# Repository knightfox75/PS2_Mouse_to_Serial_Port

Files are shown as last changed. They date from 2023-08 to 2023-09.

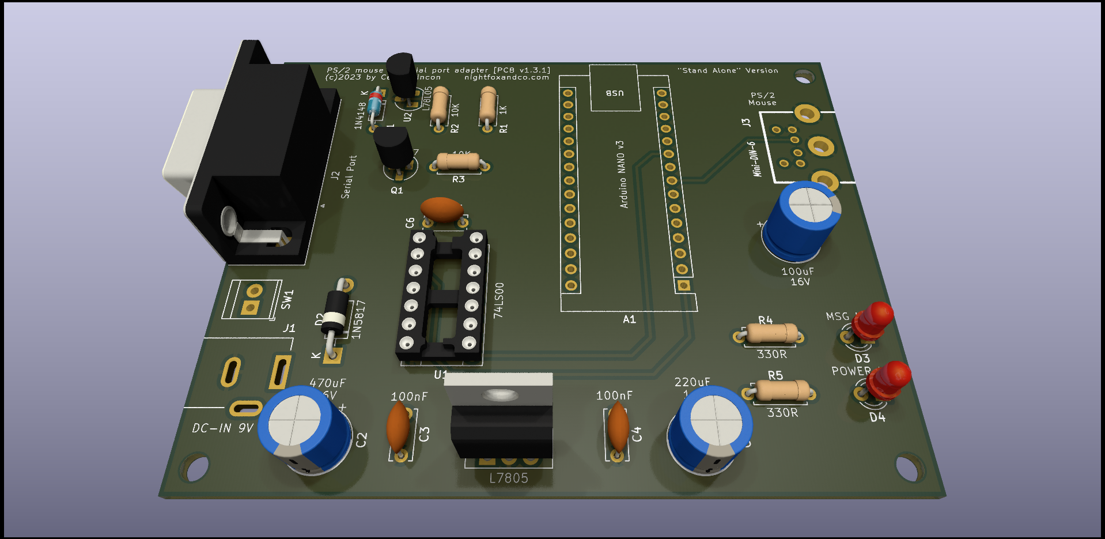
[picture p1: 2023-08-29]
schematics/Stand_Alone/PBC_preview/ps2_mouse_to_serial_port_adapter_stand_alone_3d.png

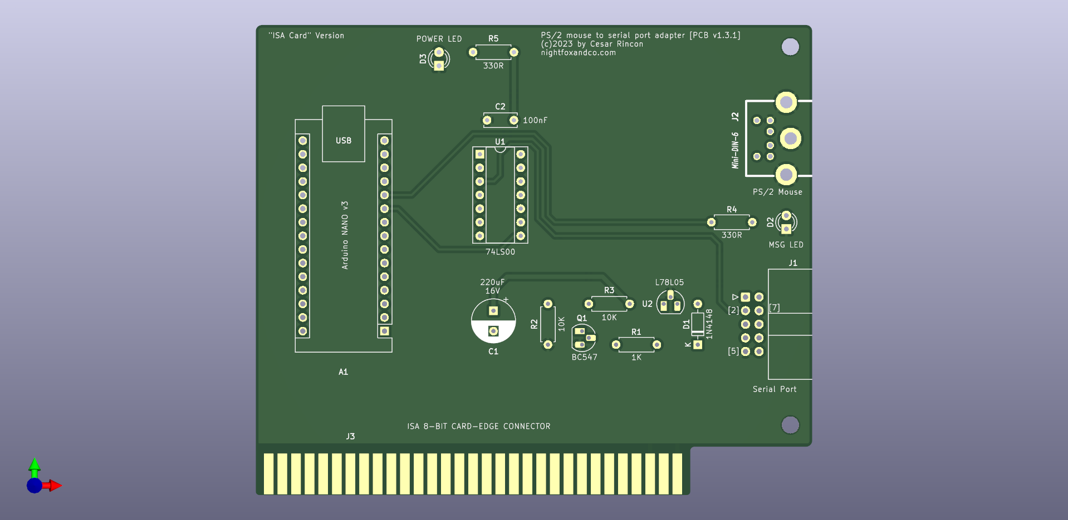
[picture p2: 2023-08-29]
schematics/ISA_Card/PBC_preview/ps2_mouse_to_serial_port_adapter_ISA_card_front.png

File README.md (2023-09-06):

# PS2_Mouse_to_Serial_Port
Un convertidor para conectar un ratón PS/2 a un puerto serie (RS-232).

1. Introducción
--------------------------------------------------------------------------------
Los ratones con conexión DB9 para puerto serie cada vez son más difíciles de encontrar (y más caros), lo que puede suponer un problema si necesitamos emplear uno en un ordenador clásico que solo disponga del puerto serie para su conexión. Después de investigar unas horas, encontré varias opciones comerciales y un par de proyectos open source que, usando placas Arduino, permitían la conexión de un ratón PS/2, o USB compatible con el protocolo PS/2 a un puerto serie.

https://github.com/Lameguy64/ps2serial
 
https://github.com/kristopher/PS2-Mouse-Arduino

Una vez documentado sobre estos proyectos y realizando un primer prototipo funcional de los mismos, decidí realizar mi propia versión del conversor.

2. Como funciona
--------------------------------------------------------------------------------
Básicamente la placa Arduino se encarga de prácticamente todo el trabajo, necesitando solo un poco de electrónica externa para su funcionamiento. Una librería de interacción con el protocolo PS/2 no permite leer la señal codificada procedente del ratón con las entradas. Dicha información se codifica en un paquete de datos en el formato que esperan los drivers de ratón mas comunes y se envían al puerto serie. Además, se monitorea la señal RTS del puerto serie por si se solicita el reinicio del envío de datos.

3. Hardware usado en el prototipo
--------------------------------------------------------------------------------
Se han realizado dos prototipos de prueba, usando las placas Arduino UNO R3 y Arduino NANO, funcionando ambas placas perfectamente. El resto de electrónica sirve para la adaptación de las señales que circulan por el puerto serie, ofreciendo cierto nivel de aislamiento y protección entre este puerto y la placa Arduino. Además, se incorporan dos diodos LED indicadores de estado, para el monitoreo del comportamiento del prototipo.

4. Que indican los LED’s de estado
--------------------------------------------------------------------------------
En mi caso he usado un LED rojo para el indicador de alimentación y un LED amarillo para el indicador de estado. Dicho indicador nos proporciona cierta información en el momento del arranque del adaptador, así como de su funcionamiento. Al encender el adaptador, si no puede detectar un ratón compatible conectado, quedará encendido de manera permanente. Dicho LED de estado parpadeará de manera intermitente una vez por segundo si ha detectado un ratón, pero no es posible iniciar la comunicación siguiendo el protocolo PS/2. Si el proceso de inicio se realiza correctamente, este LED emitirá 3 parpadeos, uno largo seguido de 2 mas cortos. Una vez iniciado el adaptador, si movemos el ratón, observaremos que este LED parpadea regularmente, quedando encendido mientras mantengamos pulsado alguno de los 3 botones del ratón. Si movemos la rueda de scroll, tambien emitira un parpadeo.
Si se recibe desde el puerto serie la señal RTS, este LED emitirá un parpadeo de aproximadamente medio segundo. Esto nos permite verificar que el driver ha detectado correctamente nuestro adaptador.

5. Capacidades extendidas
--------------------------------------------------------------------------------
Dado que este proyecto (en especial la placa ISA) está destinado a ordenadores sin puerto PS/2 (normalmente 486 y anteriores), usando el sistema operativo MS-DOS o Windows 3.11 y anteriores, junto con el hecho de que actualmente casi todos los ratones PS/2 son ópticos y disponen de la rueda de scroll, sumándole que para estos ordenadores casi ningún programa hace uso de la rueda de scroll, he decidido usar dicha rueda para ajustar a tiempo real la velocidad de desplazamiento del cursor. Dado que, según la resolución de pantalla, programa o modelo de ratón esta puede ser diferente, creo que es una característica útil. La velocidad seleccionada se conservará hasta que apaguemos el adaptador (o el ordenador en el caso de la placa ISA), no viendose afectada por el reinicio del sistema. Si queremos guardar la velocidad actual de manera permanente, deberemos de mantener pulsados los botones izquierdo y derecho de manera simultanea durante 5 segundos, observando que el LED de estado se apaga transcurrido ese tiempo. Esto nos indica que la configuración de ha almacenado de manera correcta. Si en algún momento deseamos restaurar la configuración por defecto, deberemos de mantener presionados ambos botones durante 10 segundos, el LED de estado se apagará a los 5 segundos, volviéndose a encender transcurridos 10 segundos. Esto indicará que la configuración se ha restaurado y almacenado con éxito.

6. Precauciones
--------------------------------------------------------------------------------
- Conectar y desconectar siempre el ratón al puerto PS/2 con el adaptador desconectado. La conexión o desconexión del ratón con el adaptador conectado a la alimentación podría causar daños al ratón y al propio adaptador. Esto también se aplica a la conexión del adaptador con el puerto serie del ordenador, siendo muy recomendable que todas las conexiones se realicen con los equipos apagados.
- Cualquier dispositivo conectado al puerto RS-232 del ordenador puede causar daños a dicho puerto o al dispositivo si este tiene algún error de montaje, por lo que se recomienda que repaséis 3 veces las conexiones antes de conectarlo a vuestro ordenador.
- Aplicable a la versión ISA, en ningún caso actualicéis el firmware del modulo Arduino con la tarjeta ISA insertada en la placa base. Retirar la tarjeta ISA o el módulo Arduino antes de conectarlo al puerto USB para su actualización. De no hacerlo, se corre el riesgo de dañar el módulo Arduino la propia placa base del ordenador.

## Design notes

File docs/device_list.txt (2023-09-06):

-------------------------------------------------------------------------------------------------------------------------
MODEL						|	POWER UP	|	DETECTED	|	MOVEMENT	|	2 BUTTONS	|	3RD BUTTON	|	WHEEL	|
-------------------------------------------------------------------------------------------------------------------------
PERIMICE-209				|	YES			|	YES			|	GOOD		|	YES			|	YES			|	YES		|
-------------------------------------------------------------------------------------------------------------------------
GENIUS EASYMOUSE			|	YES			|	YES			|	BAD			|	NO			|	N/A			|	N/A		|
-------------------------------------------------------------------------------------------------------------------------
HP 537748-001				|	YES			|	YES			|	GOOD		|	YES			|	YES			|	YES		|
-------------------------------------------------------------------------------------------------------------------------
LYNX-M9	(USB)				|	YES			|	YES			|	GOOD		|	YES			|	YES			|	YES		|
-------------------------------------------------------------------------------------------------------------------------
LOGITECH USB WHELLMOUSE		|	YES			|	YES			|	GOOD		|	NO			|	NO			|	YES		|
-------------------------------------------------------------------------------------------------------------------------
SATYCON 3D MOUSE			|	YES			|	YES			|	ACCEPTABLE	|	YES			|	YES			|	YES		|
-------------------------------------------------------------------------------------------------------------------------
LOGITECH M-SBJ96			|	YES			|	YES			|	GOOD		|	YES			|	YES			|	YES		|
-------------------------------------------------------------------------------------------------------------------------

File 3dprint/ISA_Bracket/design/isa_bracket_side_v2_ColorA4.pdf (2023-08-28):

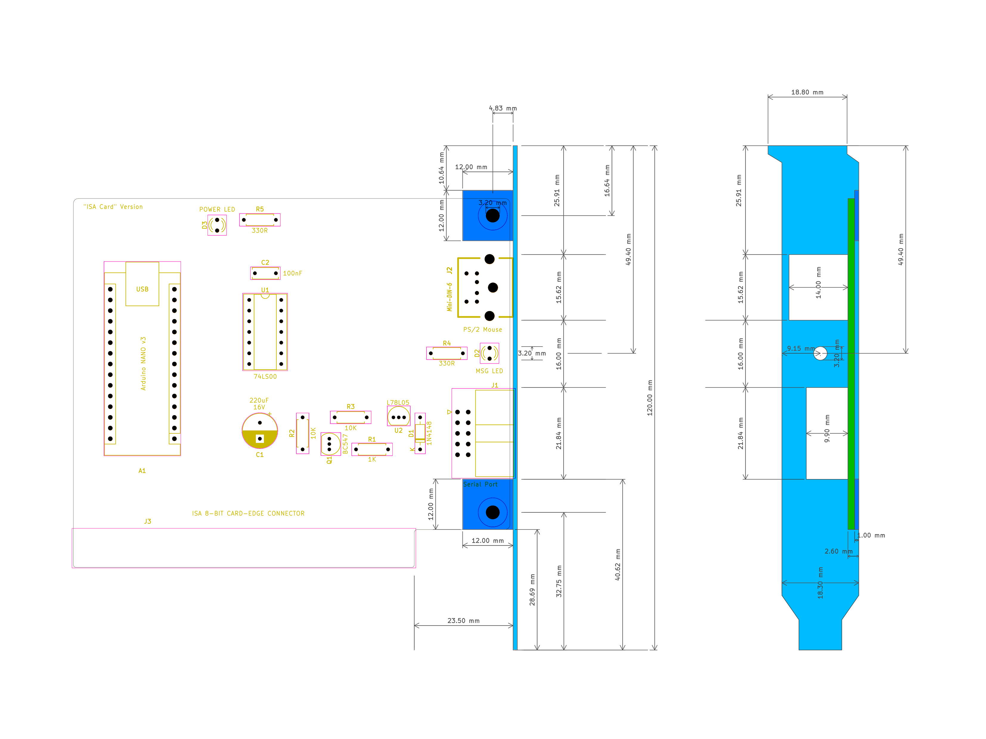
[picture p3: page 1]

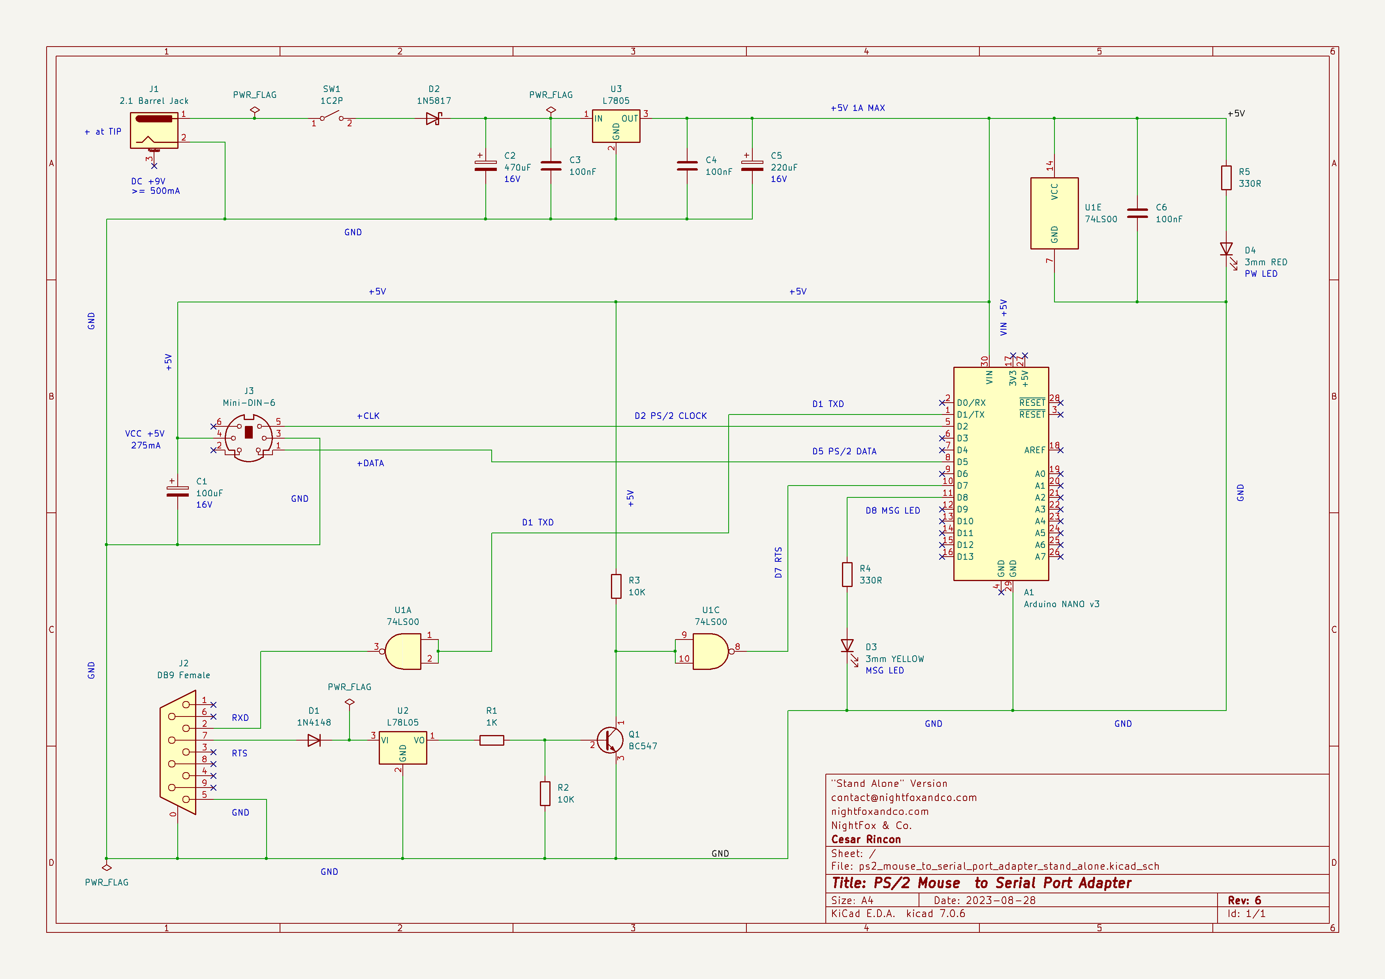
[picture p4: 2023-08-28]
schematics/Stand_Alone/Schematic/ps2_mouse_to_serial_port_adapter_stand_alone.png

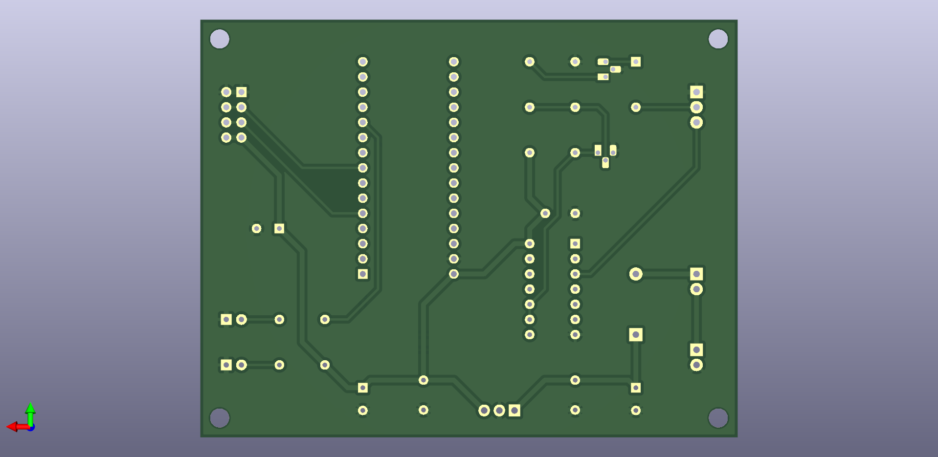
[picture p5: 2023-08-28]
schematics/In_a_Box/PBC_preview/ps2_mouse_to_serial_port_adapter_in_a_box_back.png

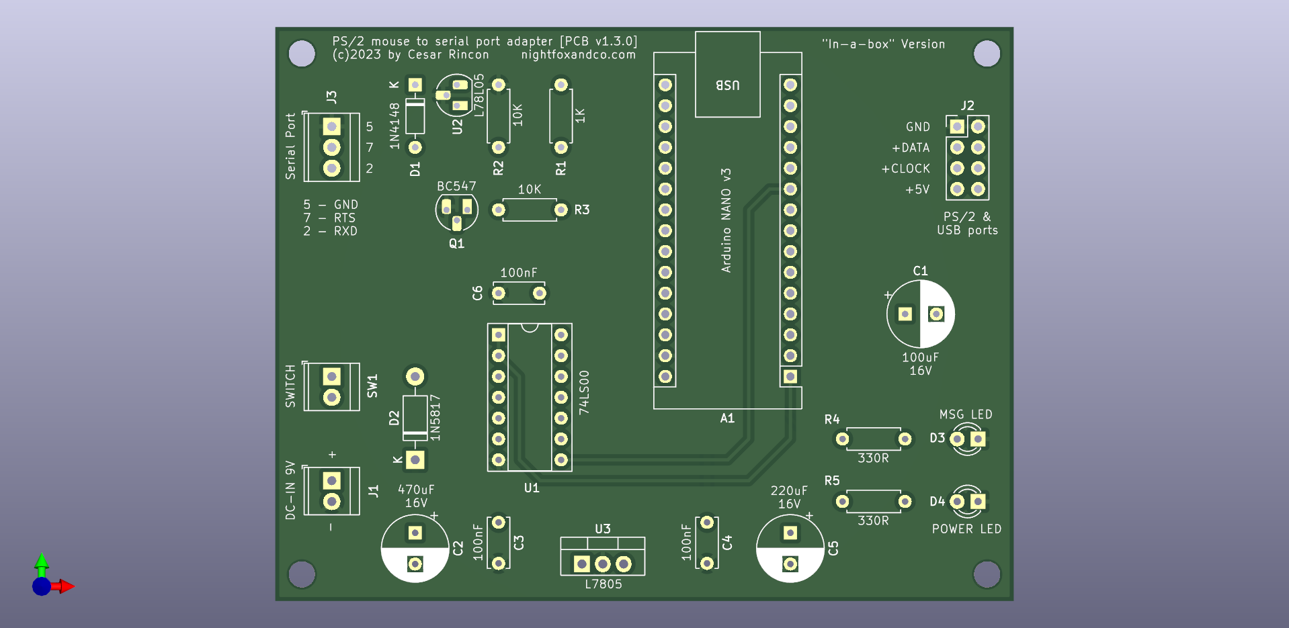
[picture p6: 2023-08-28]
schematics/In_a_Box/PBC_preview/ps2_mouse_to_serial_port_adapter_in_a_box_front.png

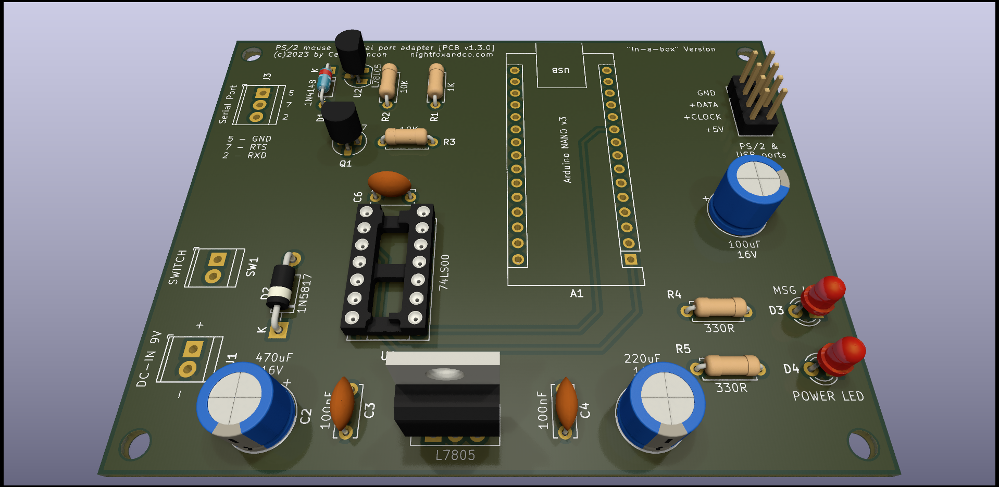
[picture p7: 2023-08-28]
schematics/In_a_Box/PBC_preview/ps2_mouse_to_serial_port_adapter_in_a_box_3d.png

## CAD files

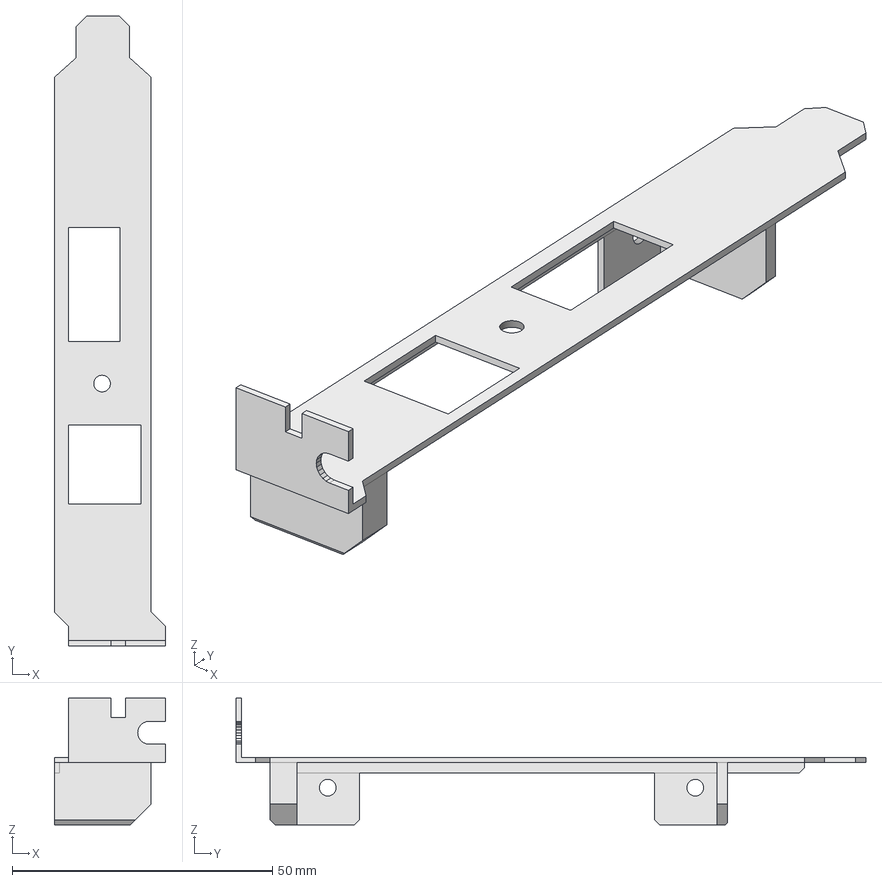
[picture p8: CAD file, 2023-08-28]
3dprint/ISA_Bracket/freecad/PS2_Serial_ISA_Bracket.FCStd
21.3 x 121.0 x 24.4 mm

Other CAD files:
3dprint/ISA_Bracket/stl/PS2_Serial_ISA_Bracket.stl

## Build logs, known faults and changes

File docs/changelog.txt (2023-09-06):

/*******************************************************************************
  
    Adaptador de mouse PS2 a puerto serie RS-232
	
	--- Archivo de registro de cambios ---

    Proyecto iniciado el Martes, 25 de Julio del 2023
    por Cesar Rincon "NightFox"

    https://nightfoxandco.com
    contact@nightfoxandco.com

    "Adaptador de mouse PS2 a puerto serie RS-232" is under MIT License
    Copyright (c) 2023 by Cesar Rincon "NightFox"

*******************************************************************************/

2023-09-06 V1.8.0
--------------------------------------------------------------------------------
- Dado que algunos modelos de ratón no funcionaban como es debido y en algunos
  casos ni encendían (PERIMICE-209), se analiza la librería usada de Arduino
  para la interfaz con el puerto PS/2. Viendo que no seguía el protocolo
  estándar PS/2, se escribe una librería con el mínimo necesario para
  interactuar con un ratón PS/2, siguiendo las normas de dicho protocolo.
- Ahora todos los comandos que se envían al ratón se verifican.
- Se añade una secuencia de encendido para activar algunos modelos de ratón
  que antes no funcionaban, como el PERIMICE-209.
- Con la librería personalizada, se añade la opción de detectar si el ratón es
  compatible con Microsoft IntelliMouse y este dispone de características
  extendidas, como la rueda de scroll. De ser así, se activa la función a
  tiempo real de cambio de velocidad del cursor usando la rueda de scroll.
- Se añade la función de guardado de la velocidad actual del cursor
  (manteniendo pulsados los botones derecho e izquierdo durante 5 segundos) y
  la función de restauración de la velocidad por defecto (manteniendo pulsados
  los botones derecho e izquierdo durante 5 segundos).
- Siguiendo el protocolo estándar PS/2, a partir de ahora no es posible la
  conexión en caliente del ratón al puerto PS/2.
- Se añaden nuevas indicaciones de estado en el LED correspondiente.

2023-08-29 V1.7.1
--------------------------------------------------------------------------------
- Modificado el ancho de la pista de alimentación del puerto PS/2
  de la placa ISA.

2023-08-28 V1.7.0
--------------------------------------------------------------------------------
- Modificadas las huellas de todas las placas para que los componentes TO92
  resulten más fáciles de soldar a mano.
- Modificadas las conexiones del conector IDC en la placa ISA para poder usar
  un cable IDC a DB9 comercial, sin necesidad de realizarle modificaciones.
- Añadido el modelo en formato FreeCad y el archivo STL del soporte para la
  placa ISA. Estos archivos estan preparados para poder realizar la impresión
  en 3D del soporte. Se recomienda un in-fill del 100%.

2023-08-24 V1.6.0
--------------------------------------------------------------------------------
- Modificada la librería PS2Mouse para evitar que la placa Arduino se quede
  colgada al iniciarse si no se detecta el mouse conectado en el puerto PS/2.
  Ahora si la inicialización del mouse falla, se reescanea el puerto a cada
  segundo. De todos modos, os recomiendo que no conectéis o desconectéis el
  mouse con el adaptador/ordenador encendido, ya que hay la posibilidad de que
  se causen daños al adaptador o al propio mouse.

2023-08-14 V1.5.1
--------------------------------------------------------------------------------
- Arreglada la serigrafía del conector MINI-DIN-6 (PS/2), la cual se
  superponía en algunas zonas de soldado.
- En todas las placas se añade el símbolo de los agujeros de montaje con el
  tamaño estándar M3.

2023-08-13 V1.5.0
--------------------------------------------------------------------------------
- Ajustadas las placas "Stand alone" y "In-a-box" al tamaño standard de
  90x70 mm.
- Añadidas a estas placas las zonas de relleno a masa (GND).
- Añadidas las serigrafias con los valores de todos los componentes en todas
  las versiones de las placas.

2023-08-12 V1.4.0
--------------------------------------------------------------------------------
- Pequeños ajustes al tamaño y contorno de la placa ISA.
- Se han añadido zonas de relleno para GND en la placa ISA.
- Sin cambios en el software.
- Importante! Recordad que aún no he podido verificar en "físico" el diseño
  de las placas, por lo que recomiendo precaución si van a ser usadas.

2023-08-12 V1.3.0
--------------------------------------------------------------------------------
- Se utiliza una referencia de versión para el proyecto, independientemente
  de las versiones de placa o software para facilitar la identificación de
  la versión actual.
- Se añade el esquema y diseño de placa para la versión "ISA".
- Se amplía el ancho de pista en las placas restantes.
- Sin cambios en el software.
- Importante! Recordad que aún no he podido verificar en "físico" el diseño
  de las placas, por lo que recomiendo precaución si van a ser usadas.

2023-08-11 V1.0.1-rev2.1
--------------------------------------------------------------------------------
- Corregido un error en la colocación del conector PS/2 en la placa
  "Stand Alone" del proyecto KiCad.
- Recordar que aún no he podido producir físicamente estas placas, por lo que
  si vais a producirlas, revisar el proyecto 3 veces en búsqueda de errores.

2023-08-10 V1.0.1-rev2
--------------------------------------------------------------------------------
- Se añade el esquema realizado en formato KiCad.
- Corregido un error en la conexión a masa del condensador C6 en el esquema
  en formato TinyCad.
- Modificadas algunas de las anotaciones en los pins de Arduino en el esquema
  en formato TinyCad.
- Añadidos los esquemas de KiCad en formato PDF y PNG.
- Añadidos los diseños de las PBC para las version "Stand Alone" y "In-a-Box"
  Estos diseños se han mandado a producción, pero aún no se han verificado.
- No hay cambios en el código.

2023-08-08 V1.0.0-stable
--------------------------------------------------------------------------------
- Modificado el esquema, añadiendo una fuente de alimentación opcional y un
  diodo de protección en la entrada de la señal RTS del puerto serie.
- No hay cambios en el código.
- Verificado el funcionamiento del prototipo con éxito en los siguientes
  equipos y configuraciones:
  · Amstrad PC1512, MS-DOS 6.22, CuteMouse 1.91 & MS Mouse 11
  · Philips NMS9100, MS-DOS 6.22, CuteMouse 1.91 & MS Mouse 11
  · Dual Core E6300, FreeDOS 1.3, CuteMouse 2.1

2023-07-26 V0.9.0-beta
--------------------------------------------------------------------------------
- Primera versión del proyecto publicada.

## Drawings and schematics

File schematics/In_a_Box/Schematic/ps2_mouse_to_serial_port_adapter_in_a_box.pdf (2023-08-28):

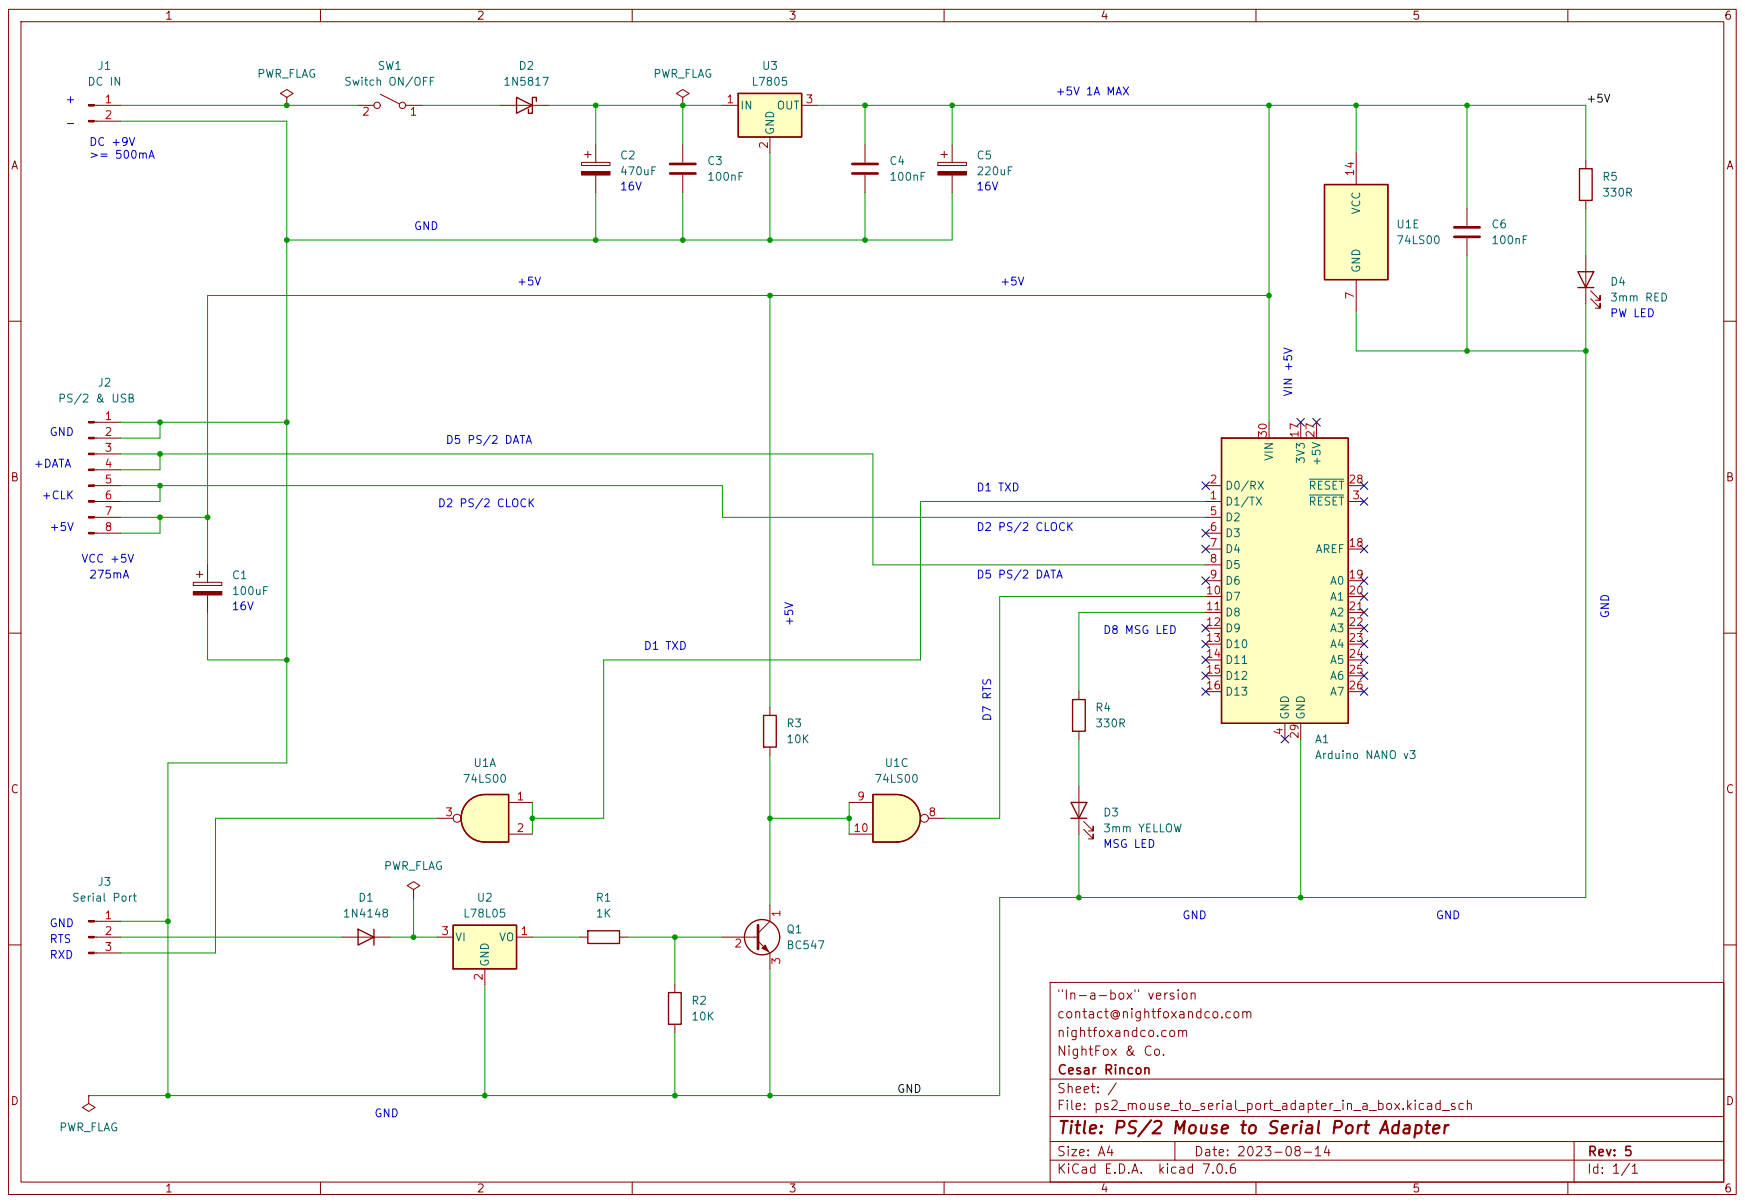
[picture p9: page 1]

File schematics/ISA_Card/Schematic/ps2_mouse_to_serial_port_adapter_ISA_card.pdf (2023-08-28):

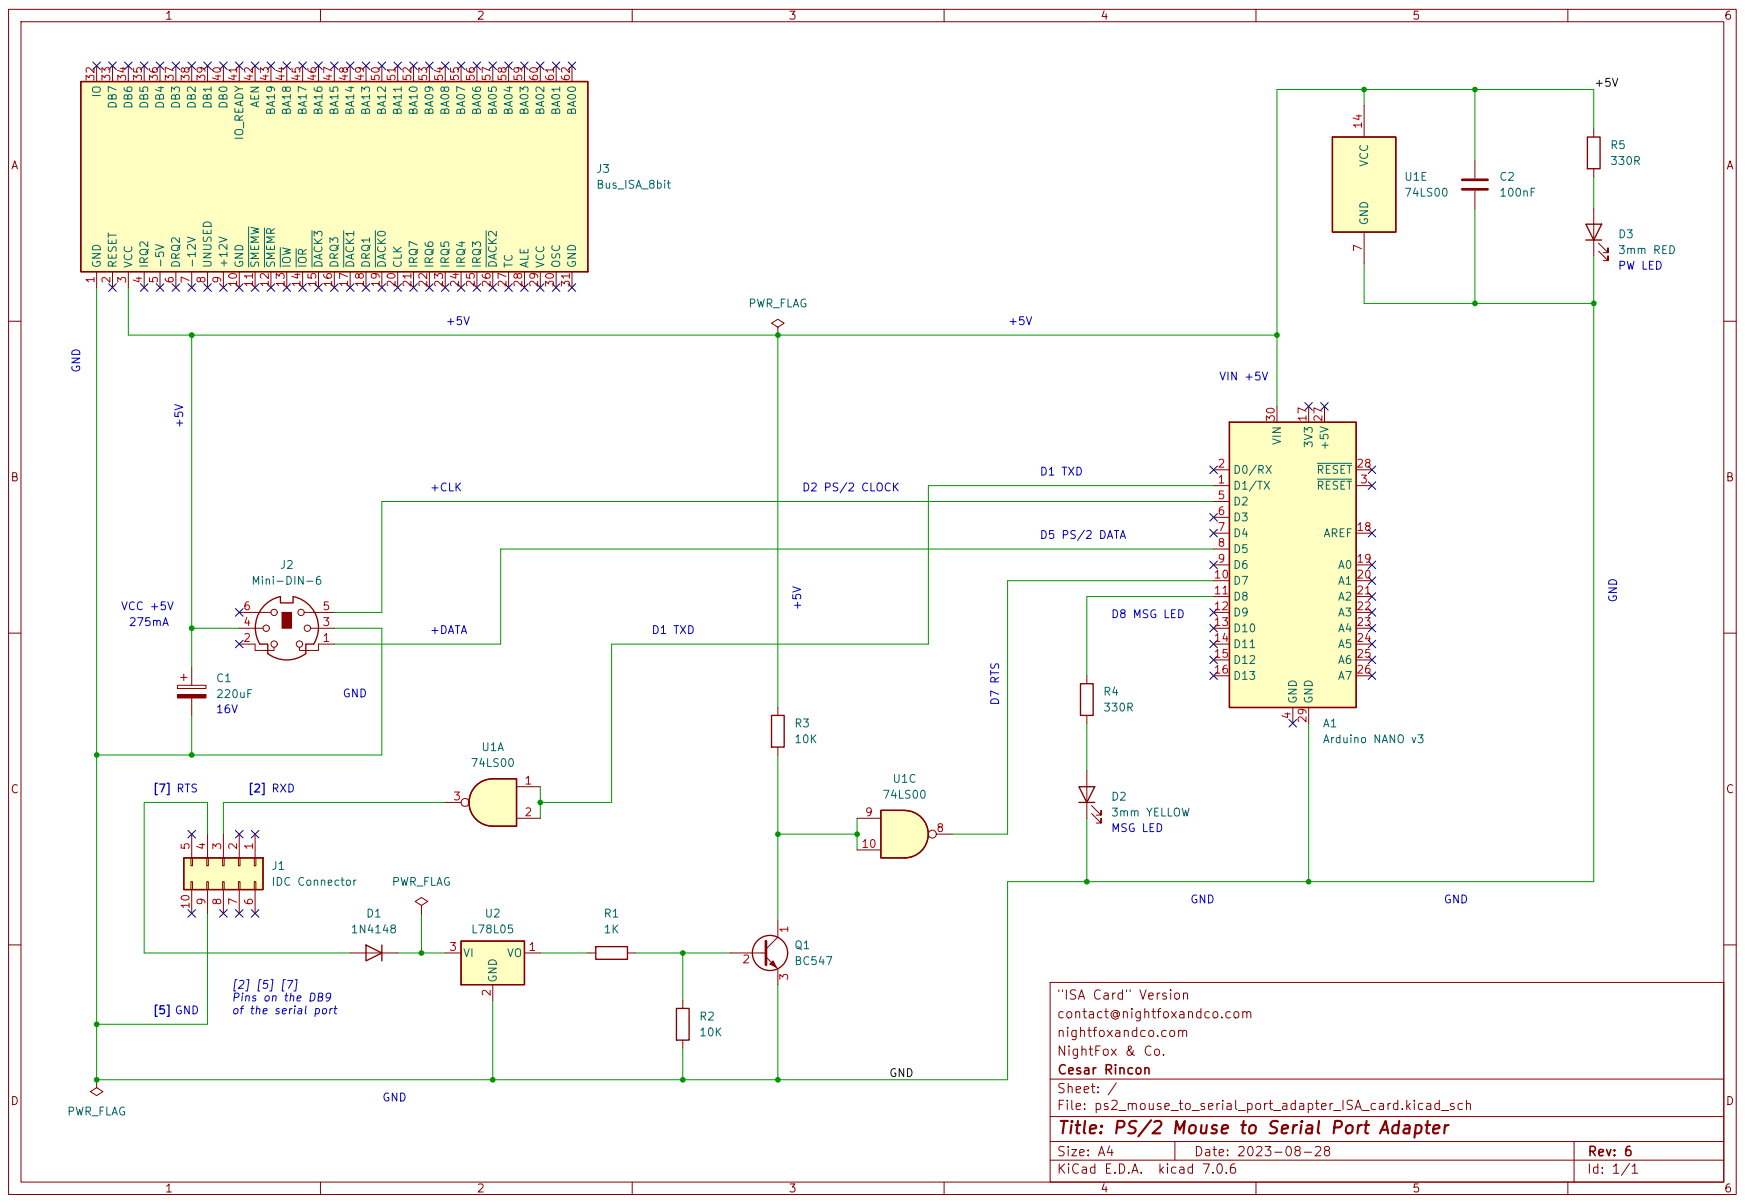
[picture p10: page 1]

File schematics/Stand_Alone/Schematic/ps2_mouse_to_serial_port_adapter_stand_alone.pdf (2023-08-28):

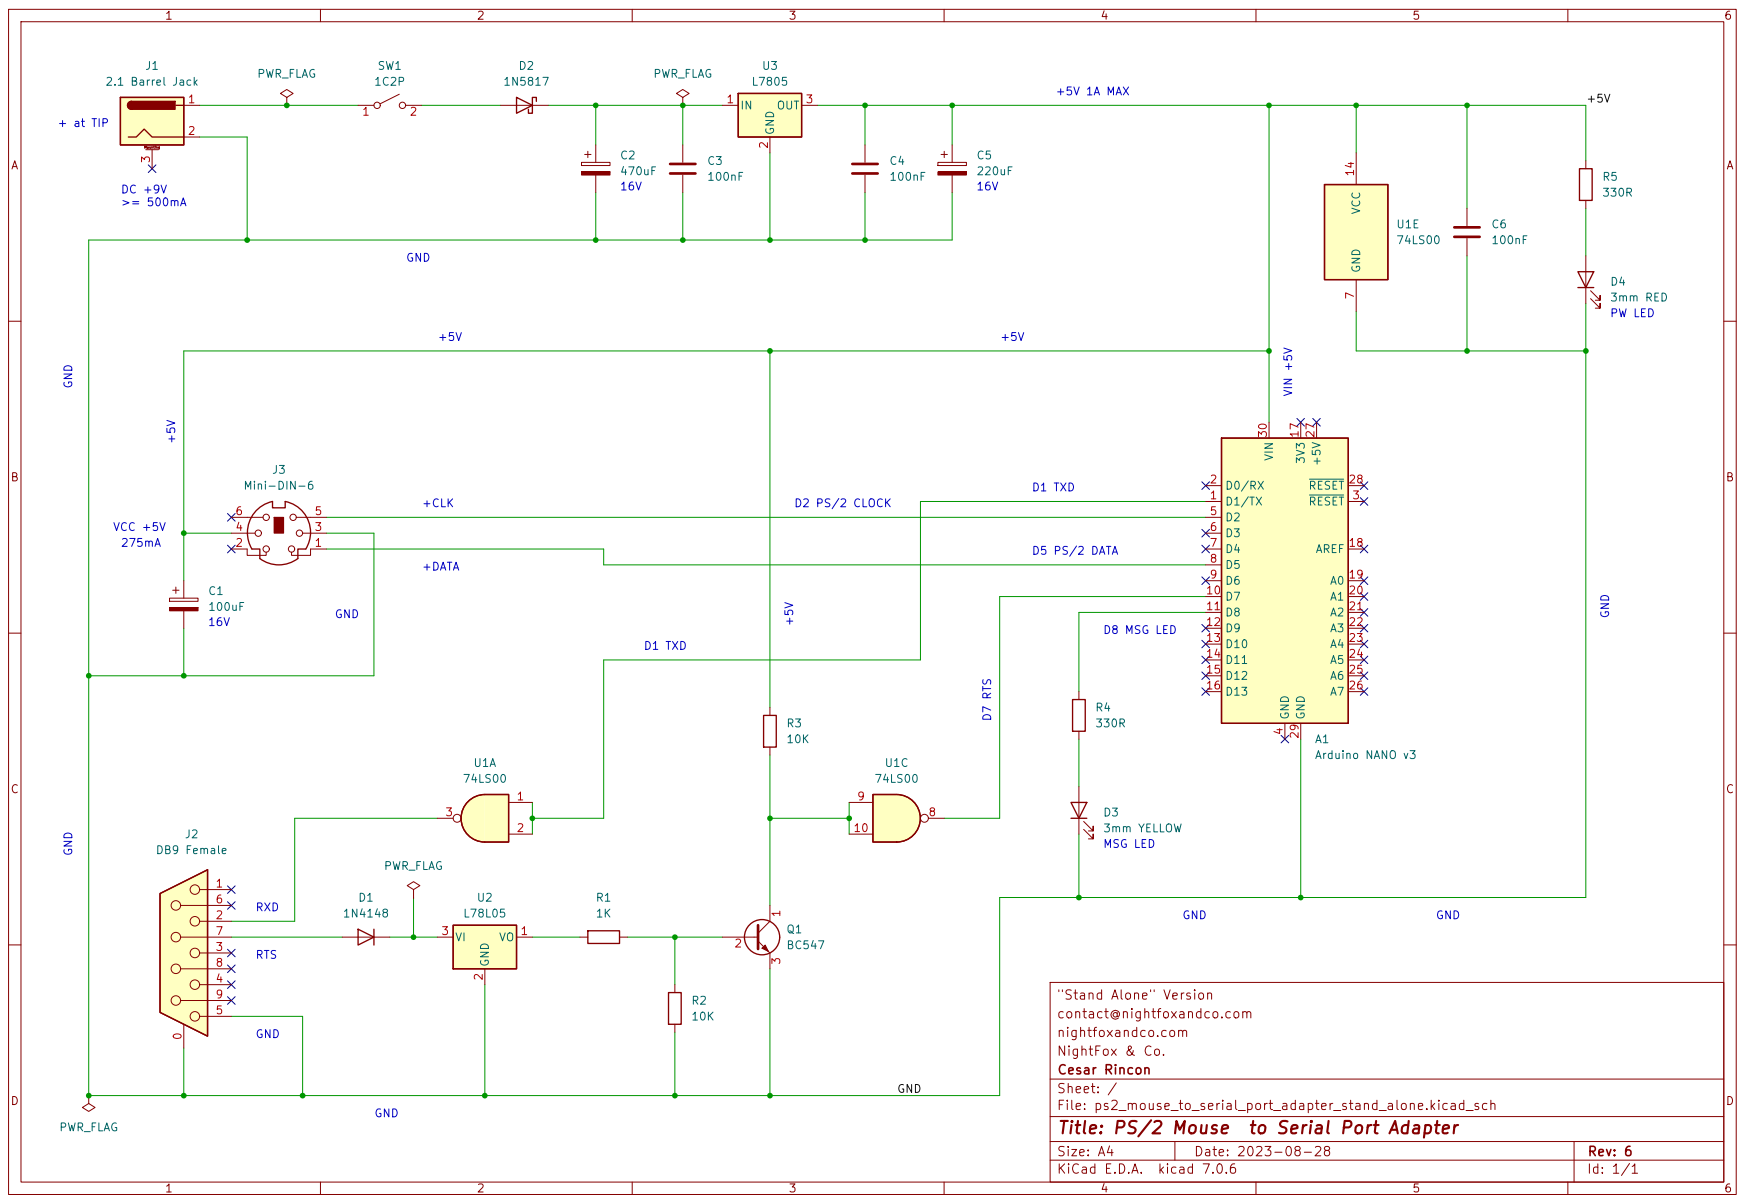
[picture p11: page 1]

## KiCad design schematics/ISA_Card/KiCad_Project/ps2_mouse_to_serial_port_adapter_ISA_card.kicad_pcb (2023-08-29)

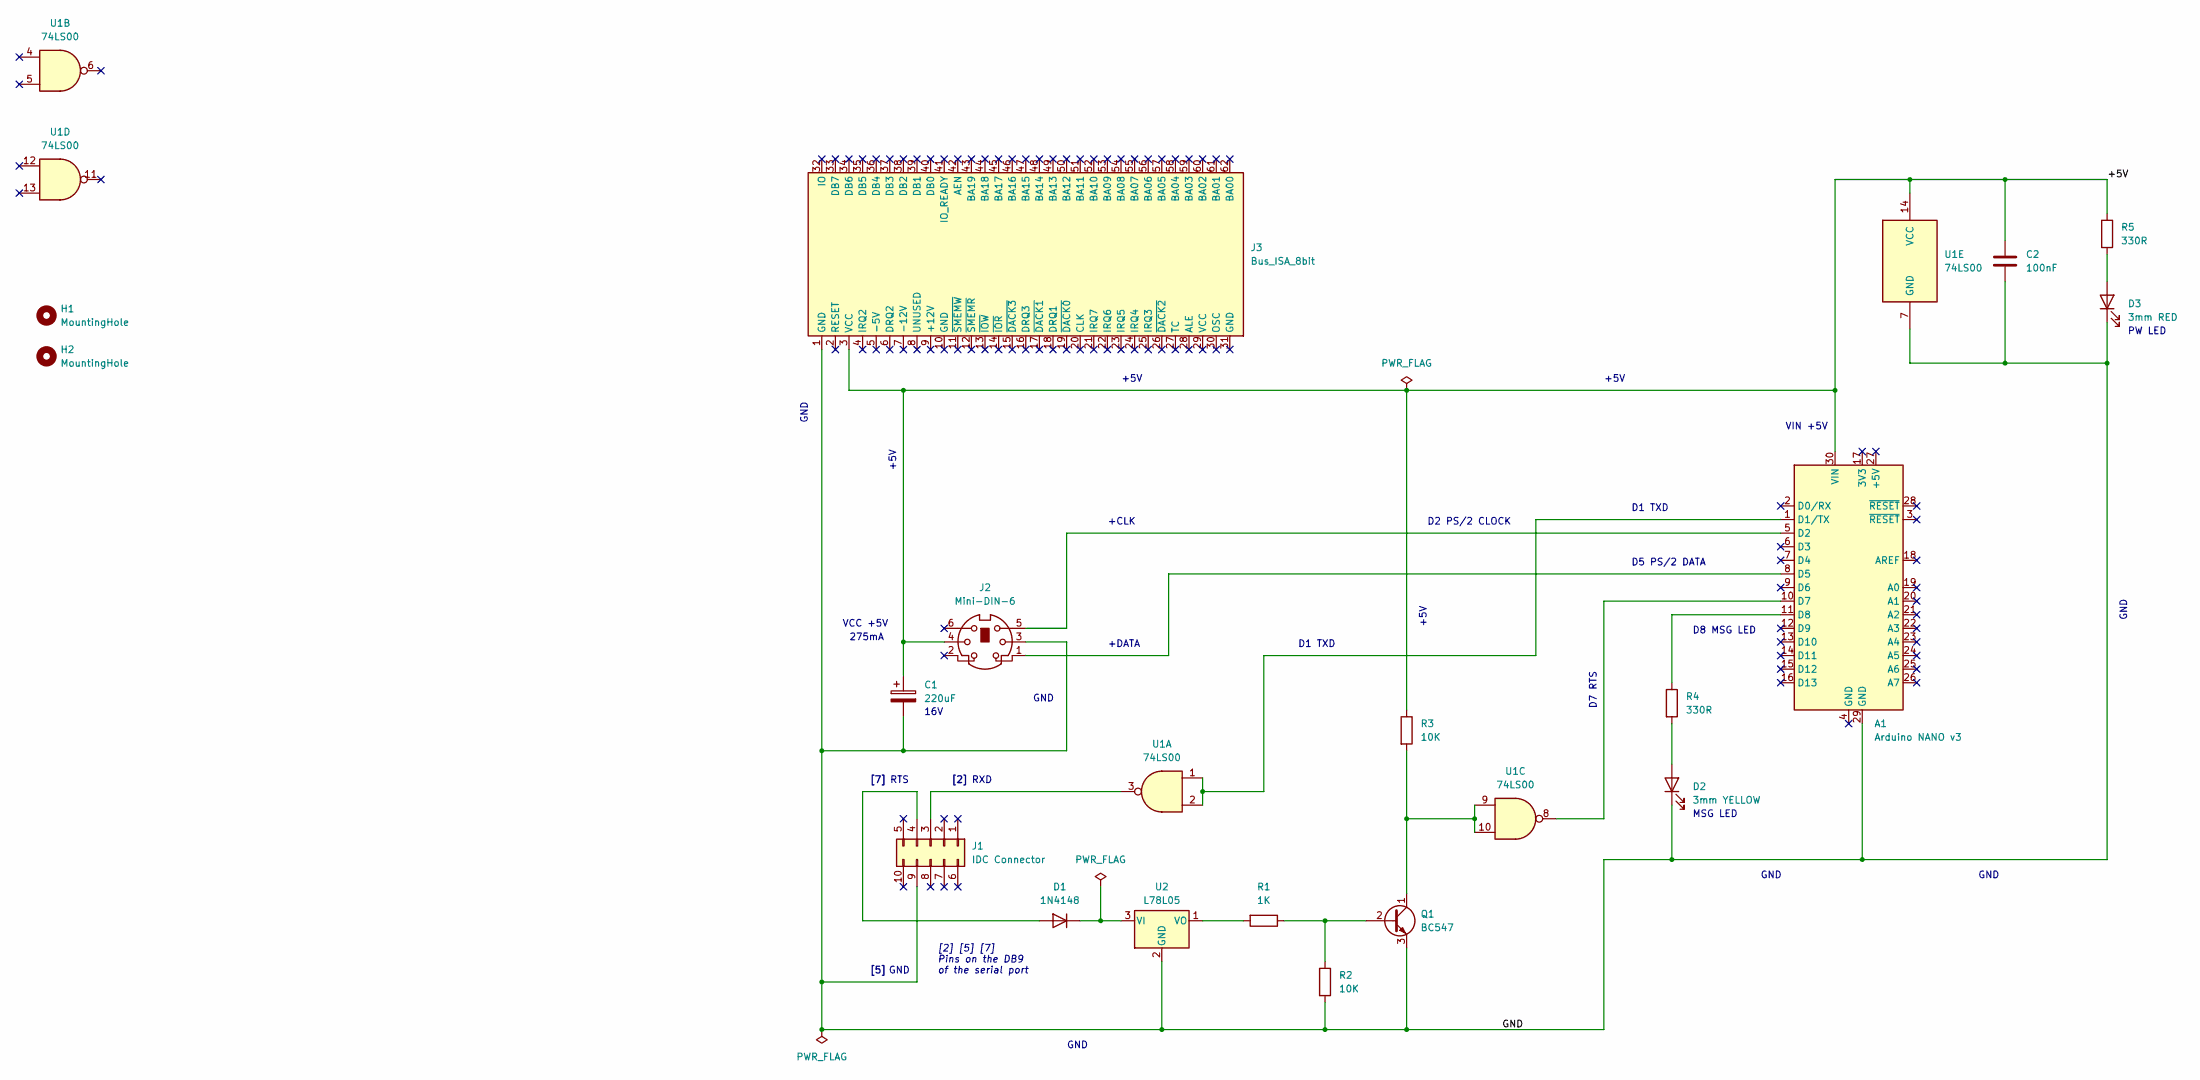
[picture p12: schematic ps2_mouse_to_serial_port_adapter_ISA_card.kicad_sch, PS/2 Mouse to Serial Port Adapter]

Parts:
A1: Arduino NANO v3; Arduino_Nano
C1: 220uF; CP_Radial_D8.0mm_P3.80mm
C2: 100nF; C_Disc_D6.0mm_W2.5mm_P5.00mm
D1: 1N4148; D_DO-35_SOD27_P7.62mm_Horizontal
D2: 3mm YELLOW; LED_D3.0mm
D3: 3mm RED; LED_D3.0mm
H1, H2: MountingHole; MountingHole_3.2mm_M3
J1: IDC Connector; IDC-Header_2x05_P2.54mm_Horizontal
J2: Mini-DIN-6; Connector_Mini_DIN_6pin
J3: Bus_ISA_8bit; BUS_AT_ISA_8BITS
Q1: BC547; TO-92_HandSolder
R1: 1K; R_Axial_DIN0207_L6.3mm_D2.5mm_P7.62mm_Horizontal
R2, R3: 10K; R_Axial_DIN0207_L6.3mm_D2.5mm_P7.62mm_Horizontal
R4, R5: 330R; R_Axial_DIN0207_L6.3mm_D2.5mm_P7.62mm_Horizontal
U1: 74LS00; DIP-14_W7.62mm_Socket
U2: L78L05; TO-92_HandSolder

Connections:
/+5V: A1.30 (VIN), C1.1, C2.1, J2.4, J3.3 (VCC), R3.1, R5.1, U1.14 (VCC)
/GND: A1.29 (GND), C1.2, C2.2, D2.1 (K), D3.1 (K), J1.9, J2.3, J2.GND, J3.1 (GND), Q1.3 (E), R2.2, U1.7 (GND), U2.2 (GND)
unnamed: A1.1 (D1/TX), U1.1, U1.2
unnamed: A1.5 (D2), J2.5
unnamed: A1.8 (D5), J2.1
unnamed: A1.10 (D7), U1.8
unnamed: A1.11 (D8), R4.1
unnamed: D1.2 (A), J1.4
unnamed: D1.1 (K), U2.3 (VI)
unnamed: D2.2 (A), R4.2
unnamed: D3.2 (A), R5.2
unnamed: J1.3, U1.3
unnamed: Q1.2 (B), R1.1, R2.1
unnamed: Q1.1 (C), R3.2, U1.9, U1.10
unnamed: R1.2, U2.1 (VO)

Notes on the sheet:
+CLK
PW LED
GND
[5]
[2]
VCC +5V
[2] [5] [7] Pins on the DB9 of the serial port
16V
MSG LED
+5V
D8 MSG LED
RTS
D5 PS/2 DATA
D1 TXD
D2 PS/2 CLOCK
VIN +5V
RXD
D7 RTS
[7]
+DATA
275mA

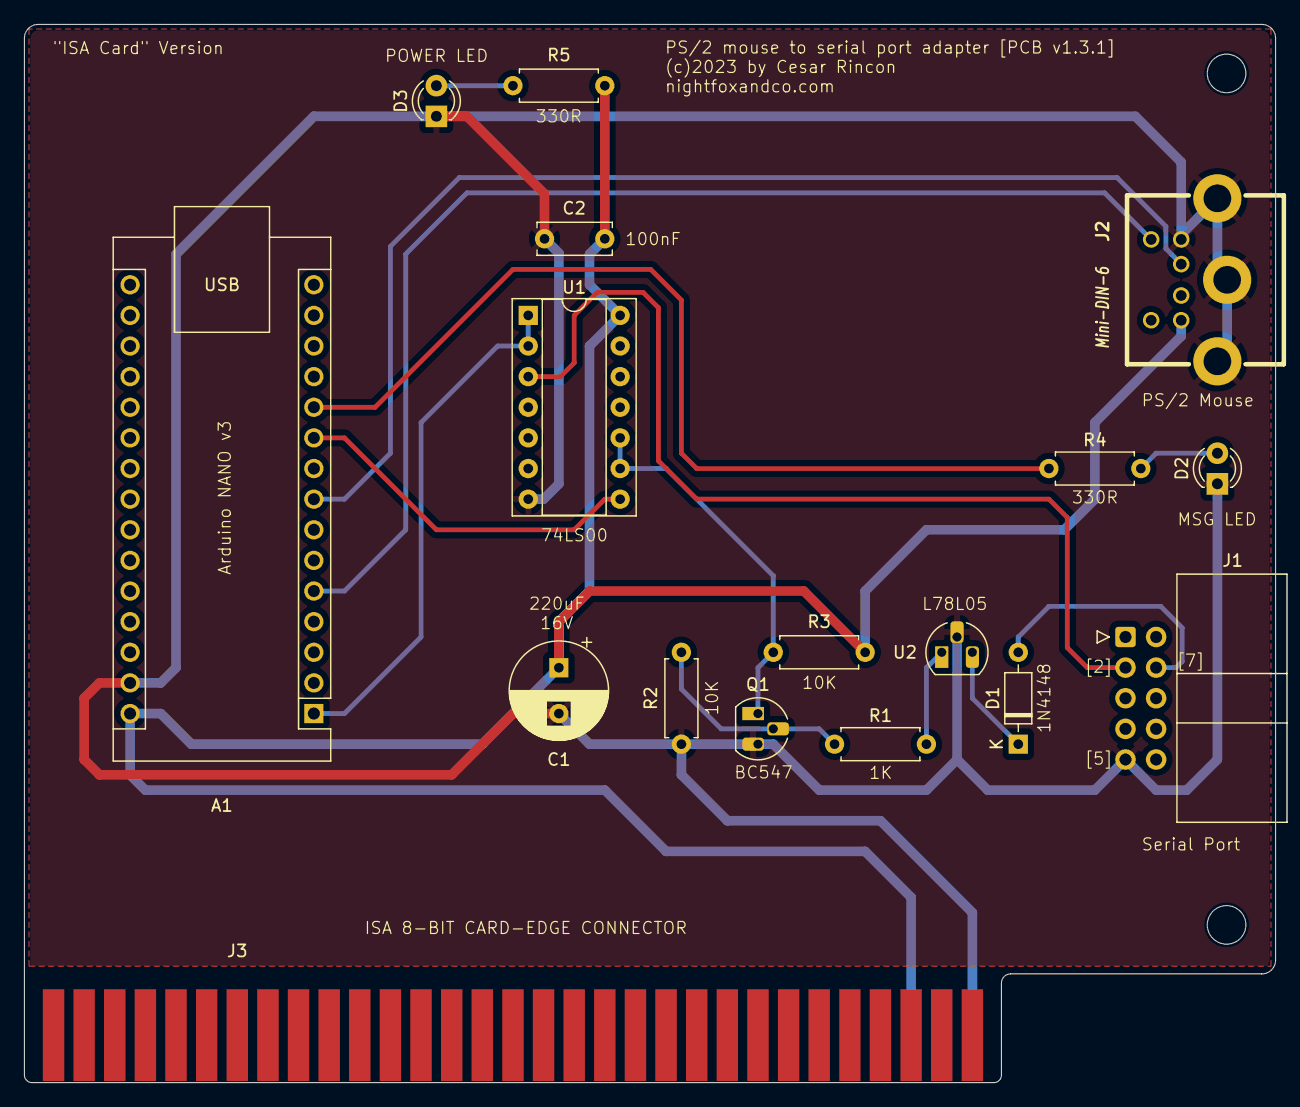
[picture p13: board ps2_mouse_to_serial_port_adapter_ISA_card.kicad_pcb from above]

Board: 2 copper layers, 103.8 x 87.8 mm, 19 parts (0 on the bottom side), 15 nets.

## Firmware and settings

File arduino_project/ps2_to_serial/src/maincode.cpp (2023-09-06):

/*******************************************************************************
  
    Adaptador de mouse PS2 a puerto serie RS-232

    Clase principal del proyecto

    Proyecto iniciado el Martes, 25 de Julio del 2023
    por Cesar Rincon "NightFox"

    https://nightfoxandco.com
    contact@nightfoxandco.com

    Basado en los siguientes proyectos de GitHub
    https://github.com/Lameguy64/ps2serial
    https://github.com/kristopher/PS2-Mouse-Arduino
  

    "Adaptador de mouse PS2 a puerto serie RS-232" is under MIT License

    Copyright (c) 2023 by Cesar Rincon "NightFox"

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
*******************************************************************************/



/*** Includes ***/
// Arduino
#include <Arduino.h>
#include <EEPROM.h>
// Proyecto
#include "config.h"
#include "ps2_mouse_interface.h"
#include "maincode.h"



/*** Constructor ***/
MainCode::MainCode() {

}



/*** Destructor ***/
MainCode::~MainCode() {

}



/*** Metodo para la configuracion inicial ***/
void MainCode::Start() {

    // Establece los valores por defecto
    SetDefaults();
    // Establece los pins
    SetPins();
    // Indica al raton PS/2 que debe encenderse
    ps2mouse.PowerUp();
    // Inicia el protocolo PS/2
    SetPs2();
    // Inicia el protocolo SERIE
    SetSerial();
    // Carga la configuracion por defecto del raton (velocidad)
    LoadMouseSpeed();

    // 3 parpadeos para indicar el bootup correcto
    for (uint8_t i = 0; i < 3; i ++) {
        digitalWrite(PIN_MSG_LED, HIGH);
        delay(100);
        digitalWrite(PIN_MSG_LED, LOW);
        delay(100);
    }
 
}



/*** Metodo del bucle de ejecucion del programa ***/
void MainCode::Update() {

    // Prepara los datos para esta iteracion
    mouse.button.left = false;
    mouse.button.right = false;
    mouse.button.middle = false;
    mouse.event = false;

    // Lectura de los datos del puerto PS/2
    // Dado que el puerto PS/2 es mucho mas rapido que el puerto SERIE,
    // estos datos se leeran "READ_LOOPS" veces para compensar la diferencia de velocidades
    for (uint8_t i = 0; i < READ_LOOPS; i ++) ReadMouse();

    // Analisis y preparacion de los datos recogidos
    ParseData();
    // LED de actividad
    ActivityLed();
    // Codifica los datos recogidos
    EncodeData();
    // Envia, si es necesario, el paquete de datos por el puero serie
    SendData();
    // Monitoreo de la señal RTS
    RtsStatusMonitor();

    // Guardado de datos?
    SaveMouseSpeed();

    // Registra el estado de los botones para la siguiente iteracion
    mouse.last.left = mouse.button.left;
    mouse.last.right = mouse.button.right;
    mouse.last.middle = mouse.button.middle;
    mouse.last.wheel = mouse.delta.wheel;

}



/*** Metodo para establecer los valores por defecto ***/
void MainCode::SetDefaults() {

    // Mouse
    mouse.position.x = 0;
    mouse.position.y = 0;
    mouse.position.wheel = 0;
    mouse.delta.x = 0;
    mouse.delta.y = 0;
    mouse.delta.wheel = 0;
    mouse.button.left = false;
    mouse.button.right = false;
    mouse.button.middle = false;
    mouse.last.left = false;
    mouse.last.right = false;
    mouse.last.middle = false;
    mouse.last.wheel = 0;
    for (uint8_t i = 0; i < 4; i ++) mouse.packet[i] = 0;
    mouse.packet_size = 3;
    mouse.event = false;
    mouse.led = 0;
    mouse.speed = MOUSE_DEFAULT_SPEED;
    mouse.save_timer = (millis() + SAVE_HELD_TIME);
    mouse.save_flag = false;
    mouse.restore_timer = (millis() + RESTORE_HELD_TIME);
    mouse.restore_flag = false;

    // RS-232
    rs232.rts = false;

}



/*** Metodo para configurar los PINS de la placa Arduino ***/
void MainCode::SetPins() {

    // Señal RTS del puerto serie
    pinMode(PIN_RTS_SIGNAL, INPUT);

    // LED de estado
    pinMode(PIN_MSG_LED, OUTPUT);
    digitalWrite(PIN_MSG_LED, LOW);

}



/*** Metodo para configurar el protocolo PS/2 ***/
void MainCode::SetPs2() {

    digitalWrite(PIN_MSG_LED, HIGH);
    
    bool ps2_ready = false;
    do {
        // Intenta iniciar el mouse ps/2, si no se consigue, reintentalo en 1 segundo
        ps2_ready |= ps2mouse.Init();
        if (!ps2_ready) {
            delay(500);
            digitalWrite(PIN_MSG_LED, LOW);
            delay(500);
            digitalWrite(PIN_MSG_LED, HIGH);
        }
    } while (!ps2_ready);

    digitalWrite(PIN_MSG_LED, LOW);

}



/*** Metodo para configurar el protocolo SERIE de la placa Arduino ***/
void MainCode::SetSerial() {

    digitalWrite(PIN_MSG_LED, HIGH);

    Serial.begin(SERIAL_BAUD_RATE, SERIAL_OPTIONS);
    while(!Serial);

    digitalWrite(PIN_MSG_LED, LOW);

}



/*** Metodo para la lectura de los datos del raton PS/2 ***/
void MainCode::ReadMouse() {

    // Lectura de los datos actuales
    ps2mouse.GetReport(mouse.data);

    // Actualiza el desplazamiento del cursor
    mouse.position.x += mouse.data[1];
    mouse.position.y -= mouse.data[2];

    // Actualiza la rueda (si esta presente)
    mouse.position.wheel += mouse.data[3];

    // Boton Izquierdo
    if (mouse.data[0] & 0x01) {
        mouse.button.left |= true;
        mouse.event |= true;
    }

    // Boton Derecho
    if (mouse.data[0] & 0x02) {
        mouse.button.right |= true;
        mouse.event |= true;
    }

    // Boton Central
    if (mouse.data[0] & 0x04) {
        mouse.button.middle |= true;
        mouse.event |= true;
        // Compensacion de retardo por la lectura de paquetes extra al pulsar el boton central
        if (mouse.button.middle && !mouse.last.middle) ps2mouse.EmptyBuffer();
    }

}



/*** Matodo para el analisis y preparacion de los datos para su envio ***/
void MainCode::ParseData() {

    // Rueda del raton
    mouse.delta.wheel = mouse.position.wheel;

    // Ajusta la velocidad del cursor con la rueda (si esta disponible)
    if (mouse.delta.wheel != mouse.last.wheel) {
        if (mouse.delta.wheel > 0) {
            mouse.speed += MOUSE_SPEED_CHANGE;
            if (mouse.speed > MOUSE_MAX_SPEED) mouse.speed = MOUSE_MAX_SPEED;
        }
        if (mouse.delta.wheel < 0) {
            mouse.speed -= MOUSE_SPEED_CHANGE;
            if (mouse.speed < MOUSE_MIN_SPEED) mouse.speed = MOUSE_MIN_SPEED;
        }
    }

    // Ajuste de velocidad
    mouse.delta.x = (mouse.position.x * mouse.speed);
    mouse.delta.y = (mouse.position.y * mouse.speed);

    // Si se detecta desplazamiento, ajusta los valores delta, reinicia los contadores y registra el evento
    if (mouse.delta.x != 0) {
        mouse.position.x = 0;
        mouse.event |= true;
        if (mouse.delta.x < -255) mouse.delta.x = -255;
        if (mouse.delta.x > 255) mouse.delta.x = 255;
    }
    if (mouse.delta.y != 0) {
        mouse.position.y = 0;
        mouse.event |= true;
        if (mouse.delta.y < -255) mouse.delta.y = -255;
        if (mouse.delta.y > 255) mouse.delta.y = 255;
    }

    // Captura el movimiento de la rueda
    if (mouse.delta.wheel != 0) {
        mouse.position.wheel = 0;
        mouse.event |= true;
        if (mouse.delta.wheel < -7) mouse.delta.wheel = -7;
        if (mouse.delta.wheel > 7) mouse.delta.wheel = 7;
    }

    // Captura los eventos por el cambio de estado al pulsar/soltar cualquier boton del mouse
    mouse.event |= (mouse.button.left != mouse.last.left);
    mouse.event |= (mouse.button.right != mouse.last.right);
    mouse.event |= (mouse.button.middle != mouse.last.middle);

}



/*** Metodo el LED de actividad del raton ***/
void MainCode::ActivityLed() {

    // Led de actividad
    if (mouse.event) {
        if (mouse.restore_flag) {
            digitalWrite(PIN_MSG_LED, HIGH);
            mouse.led = MOUSE_BLINK_DELAY;   
        } else if (mouse.save_flag) {
            digitalWrite(PIN_MSG_LED, LOW);
            mouse.led = MOUSE_BLINK_DELAY;
        } else if (mouse.button.left || mouse.button.right || mouse.button.middle || (mouse.delta.wheel != 0)) {
            digitalWrite(PIN_MSG_LED, HIGH);
            mouse.led = MOUSE_BLINK_DELAY;
        } else {
            mouse.led --;
            if (mouse.led <= 0) {
                mouse.led = MOUSE_BLINK_DELAY;
                digitalWrite(PIN_MSG_LED, !digitalRead(PIN_MSG_LED));
            }
        }
    } else {
        mouse.led = MOUSE_BLINK_DELAY;
        digitalWrite(PIN_MSG_LED, LOW);
    }

}



/*** Metodo para codificacion del paquete de datos ***/
void MainCode::EncodeData() {

    // Si no hay eventos registrados sal
    if (!mouse.event) return;

    // Prepara los datos de codificacion
    uint8_t x = mouse.delta.x;
    uint8_t y = mouse.delta.y;
    uint8_t rb = mouse.button.right ? 1 : 0;
    uint8_t lb = mouse.button.left ? 1 : 0;
    uint8_t mb = mouse.button.middle ? 1 : 0;
    mouse.packet_size = 3;

    // Codificacion del byte 0 del paquete
    mouse.packet[0] =
        ((x >> 6) & 0x03)                   // Ultimos 2 bits del delta X
        |
        (((y >> 6) & 0x03) << 2)            // Ultimos 2 bits del delta Y
        |
        ((rb << 4) | (lb << 5) | 0x40)      // Estados de los botones derecho e izquierdo y el ID de paquete
    ;

    // Codificacion del byte 1 del paquete
    mouse.packet[1] = (x & 0x3F);           // Primeros 6 bits del delta X
    // Codificacion del byte 2 del paquete
    mouse.packet[2] = (y & 0x3F);           // Primeros 6 bits del delta Y

    // Codificacion del byte 3 del paquete (estado del boton central)
    if (mouse.button.middle) {      // Envia el 4º paquete mientras el boton central este presionado
        mouse.packet[3] = 0x20;
        mouse.packet_size = 4;
    } else {                        // Envia el 4º paquete una vez cuando se suelte el boton central
        if (mouse.last.middle && !mouse.button.middle) {
            mouse.packet[3] = 0x00;
            mouse.packet_size = 4;
        }
    }

}



/*** Metodo para el envio del paquete de datos al puerto serie ***/
void MainCode::SendData() {

    // Fase 1 - Envio del paquete de datos en caso de evento del raton
    if (mouse.event) Serial.write(mouse.packet, mouse.packet_size);

    // Fase 2 - Envio de un paquete adicional en caso de evento del boton central
    if (mouse.button.middle != mouse.last.middle) {
        mouse.packet[0] = 0x40;
        mouse.packet[1] = 0x00;
        mouse.packet[2] = 0x00;
        mouse.packet_size = 3;
        Serial.write(mouse.packet, mouse.packet_size);
    }

}



/*** Metodo para el monitoreo del estado de la señal RTS del puerto serie ***/
void MainCode::RtsStatusMonitor() {

    if (digitalRead(PIN_RTS_SIGNAL)) {

        // Si no se ha recibido la señal previamente
        if (!rs232.rts) {

            // Envia los bytes de inicializacion del protocolo
            delay(14);
            Serial.write(0x4D);         // char: 'M'
            delay(63);
            Serial.write(0x33);         // char: '3'

            // Reinicia el estado de los botones
            mouse.button.left = false;
            mouse.button.right = false;
            mouse.button.middle = false;

            // Reinicia el registro de posicion
            mouse.position.x = 0;
            mouse.position.y = 0;
            mouse.position.wheel = 0;

            // Registra el cambio de flag del RTS
            rs232.rts = true;

            // Indicalo en el led de activadad
            digitalWrite(PIN_MSG_LED, HIGH);
            delay(500);
            digitalWrite(PIN_MSG_LED, LOW);

        }

    } else {

        rs232.rts = false;      // Flag de señal recibida abajo

    }

}


/*** Guarda la configuracion de velocidad ***/
void MainCode::SaveMouseSpeed() {

    // Si no estan presionados ambos botones, reinicia los temporizadores y sal
    if (!mouse.button.left || !mouse.button.right) {
        mouse.save_timer = (millis() + SAVE_HELD_TIME);
        mouse.restore_timer = (millis() + RESTORE_HELD_TIME);
        // Reinicia flags de guardado si se sueltan ambos botones
        if (!mouse.button.left && !mouse.button.right) {
            mouse.save_flag = false;
            mouse.restore_flag = false;
        }
        // Sal
        return;
    }

    // Datos
    bool save_now = false;
    uint8_t data = 0;

    // Guardado de los parametros actuales
    if (!mouse.save_flag) {
        if ((millis() >= mouse.save_timer)) { 
            data = (uint8_t)(mouse.speed * 100.0f);
            mouse.save_flag = true;
            save_now = true;
        }
    }

    // Reinicio y guardado de los parametros
    if (!mouse.restore_flag) {
        if ((millis() >= mouse.restore_timer)) { 
            mouse.speed = MOUSE_DEFAULT_SPEED;
            data = (uint8_t)(mouse.speed * 100.0f);
            mouse.restore_flag = true;
        }
    }

    // Guarda los parametros en la EEPROM si se solicita
    if (save_now) {
        EEPROM.write(0x00, CHK0);
        EEPROM.write(0x01, data);
        EEPROM.write(0x02, CHK2);
    }

}



/*** Lee la configuracion de velocidad ***/
void MainCode::LoadMouseSpeed() {

    uint8_t b0 = EEPROM.read(0x00);
    uint8_t data = EEPROM.read(0x01);
    uint8_t b2 = EEPROM.read(0x02);

    if ((b0 != CHK0) || (b2 != CHK2)) {
        // Si los datos son invalidos, crealos por defecto
        data = (uint8_t)(MOUSE_DEFAULT_SPEED * 100.0f);
        EEPROM.write(0x00, CHK0);
        EEPROM.write(0x01, data);
        EEPROM.write(0x02, CHK2);
    }

    mouse.speed = ((float)data / 100.0f);
    if (mouse.speed < MOUSE_MIN_SPEED) mouse.speed = MOUSE_MIN_SPEED;
    if (mouse.speed > MOUSE_MAX_SPEED) mouse.speed = MOUSE_MAX_SPEED;

}

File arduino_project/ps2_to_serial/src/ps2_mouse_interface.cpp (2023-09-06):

/*******************************************************************************
  
    Interfaz de raton PS/2 para Arduino
    Version 1.0.0-STABLE

    Proyecto iniciado el Martes, 02 de Septiembre del 2023
    por Cesar Rincon "NightFox"

    https://nightfoxandco.com
    contact@nightfoxandco.com

    Basado en los siguientes proyectos de GitHub
    https://github.com/kristopher/PS2-Mouse-Arduino

    Bibliografia
    https://isdaman.com/alsos/hardware/mouse/ps2interface.htm
    https://www.burtonsys.com/ps2_chapweske.htm
    https://wiki.osdev.org/PS/2_Mouse
  

    "Interfaz de raton PS/2 para Arduino" is under MIT License

    Copyright (c) 2023 by Cesar Rincon "NightFox"

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
*******************************************************************************/



/*** Includes ***/
// Arduino
#include <Arduino.h>
// Proyecto
#include "config.h"
#include "ps2_mouse_interface.h"



/*** Constructor ***/
Ps2MouseInterface::Ps2MouseInterface(uint8_t _clock_pin, uint8_t _data_pin, uint8_t _sample_rate, uint8_t _resolution) {

    clock_pin = _clock_pin;
    data_pin = _data_pin;
    sample_rate = _sample_rate;
    resolution = _resolution;
    data_length = 3;

}



/*** Destructor ***/
Ps2MouseInterface::~Ps2MouseInterface() {

}



/*** Indica al raton que debe encenderse (requerido en algunos modelos) ***/
void Ps2MouseInterface::PowerUp() {

    // Secuencia para el power-up del raton
    delay(POWER_UP_DELAY);
    PinPullUp(clock_pin);
    PinPullUp(data_pin);
    delay(POWER_UP_DELAY);

}



/*** Inicia el puerto/raton ***/
bool Ps2MouseInterface::Init() {

    // Rutina de inicializacion estandar
    for (uint8_t i = 0; i < 3; i++) {
        // Envia el comando reset
        WriteByte(CMD_RESET);
        // Lee el "reconocido"
        if (ReadByte() != CMD_ACKNOWLEDGE) return false;
        // Lee el "ok"
        if (ReadByte() != CMD_SELF_TEST) return false;
        // Lee el "mouse ID"
        mouse_id = ReadByte();
    }

    // Fuerza los valores por defecto del protocolo ps/2
    // Sampling rate = 100, Resolution = 4 counts/mm, Scaling = 1:1, Disable Data Reporting,
    // resetea los contadores y entra en modo stream
    WriteByte(CMD_SET_DEFAULTS);
    if (ReadByte() != CMD_ACKNOWLEDGE) return false;

    // Verifica si el raton conectado tiene capacidades extendidas
    if (!IntelliMouseCheck()) return false;
    data_length = (mouse_id == INTELLI_MOUSE) ? 4:3;

    // Sample Rate
    WriteByte(CMD_SET_SAMPLE_RATE);
    if (ReadByte() != CMD_ACKNOWLEDGE) return false;
    WriteByte(sample_rate);
    if (ReadByte() != CMD_ACKNOWLEDGE) return false;

    // Scaling
    WriteByte(CMD_SET_SCALING_1_1);
    if (ReadByte() != CMD_ACKNOWLEDGE) return false;

    // Resolution
    WriteByte(CMD_SET_RESOLUTION);
    if (ReadByte() != CMD_ACKNOWLEDGE) return false;
    WriteByte(resolution);
    if (ReadByte() != CMD_ACKNOWLEDGE) return false;

    // Indica al raton que empiece con el envio de datos
    WriteByte(CMD_ENABLE_DATA_REPORTING);
    if (ReadByte() != CMD_ACKNOWLEDGE) return false;

    // Informa del proceso de inicio correcto
    return true;

}



/*** Pon un pin en PULL-UP [1, alta impedancia] ***/
void Ps2MouseInterface::PinPullUp(uint8_t pin) {

    pinMode(pin, INPUT_PULLUP);

}



/*** Pon un pin en PULL-DOWN [0] ***/
void Ps2MouseInterface::PinPullDown(uint8_t pin) {

    pinMode(pin, OUTPUT);
    digitalWrite(pin, 0);

}



/*** Escribe un Byte en el pin de datos ***/
void Ps2MouseInterface::WriteByte(uint8_t dt) {
    
    // Calcula la paridad
    uint8_t parity = 0x01;
    uint8_t d = dt;
    while(d != 0) {
        parity ^= (d & 0x01);
        d >>= 1;
    }

    // Prepara el paquete de datos (11 bits)
    bits_buffer = 0x00;                     // BIT inicial [0], siempre 0
    bits_buffer |= ((dt & 0xFF) << 1);      // BITS de datos [1 al 8]
    bits_buffer |= ((parity & 0x01) << 9);  // BIT de paridad [9]
    bits_buffer |= (1 << 10);               // BIT de parada [10], siempre 1

    // Indica al puerto que quieres enviar datos
    PinPullDown(clock_pin);
    delayMicroseconds(RTS_CLOCK_TIME);

    // Envia el BIT de inicio [0]
    PinPullDown(data_pin);
    PinPullUp(clock_pin);
    while(digitalRead(clock_pin));

    // Envio del paquete de datos y paridad (bits del 1 al 9)
    for (uint8_t i = 1; i <= 9; i ++) WriteBit((bits_buffer >> i) & 0x01);

    // Libera la linea de datos (bit de parada [10])
    PinPullUp(data_pin);
    while(digitalRead(data_pin));
    while(digitalRead(clock_pin));

    // Espera a que el dispositivo vuelva al modo IDLE
    while (!digitalRead(clock_pin) || !digitalRead(data_pin));

}



/*** Escribe un bit en el pin de datos ***/
void Ps2MouseInterface::WriteBit(bool bit) {

    if (bit) {
        PinPullUp(data_pin);
    } else {
        PinPullDown(data_pin);
    }

    // Espera un ciclo de reloj
    while (!digitalRead(clock_pin));
    while (digitalRead(clock_pin));

}



/*** Lee un byte del pin de datos ***/
uint8_t Ps2MouseInterface::ReadByte() {

    // Datos a devolver
    uint8_t dt = 0xFF;

    // Indica al puerto que quieres recibir datos
    PinPullUp(clock_pin);
    PinPullUp(data_pin);
    delayMicroseconds(RTR_CLOCK_TIME);

    // Lee el paquete de datos
    bits_buffer = 0x00;
    for (uint8_t i = 0; i < 11; i ++) bits_buffer |= ReadBit() ? (1 << i):0x00;
    
    // Indica al puerto que espera para el envio del siguiente paquete de datos
    PinPullDown(clock_pin);
    delayMicroseconds(RTS_PAUSE_TIME);

    // Devuelve los datos (devulve 0 si os bits de inicio y parada no son correctos)
    if (!(bits_buffer & 0x01) && ((bits_buffer >> 10) & 0x01)) dt = ((bits_buffer >> 1) & 0xFF);
    return dt;

}



/*** Lee un bit del pin de datos ***/
bool Ps2MouseInterface::ReadBit() {

    while(digitalRead(clock_pin));
    bool b = digitalRead(data_pin);
    while(!digitalRead(clock_pin));
    return b;

}



/*** Habilita el envio de datos en modo stream ***/
bool Ps2MouseInterface::EnableDataReporting() {

    WriteByte(CMD_ENABLE_DATA_REPORTING);
    return (ReadByte() == CMD_ACKNOWLEDGE) ? true:false;

}




/*** Deshabilita el envio de datos en modo stream ***/
bool Ps2MouseInterface::DisableDataReporting() {

    WriteByte(CMD_DISABLE_DATA_REPORTING);
    return (ReadByte() == CMD_ACKNOWLEDGE) ? true:false;

}
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

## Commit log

2023-07-26 PS/2 Mouse to Serial v0.9.0-beta
    Initial release.
    [ps2_mouse_to_serial_rev_1_0.dsn]
2023-08-08 V1.0.0-stable
    - Modificado el esquema, añadiendo una fuente de alimentación opcional y un diodo de protección en la entrada de la señal RTS del puerto serie.
    - No hay cambios en el código.
    - Verificado el funcionamiento del prototipo con éxito en los siguientes
    equipos y configuraciones:
    · Amstrad PC1512, MS-DOS 6.22, CuteMouse 1.91 & MS Mouse 11
    · Philips NMS9100, MS-DOS 6.22, CuteMouse 1.91 & MS Mouse 11
    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
    [ps2_mouse_to_serial_rev_1_0.dsn, ps2_mouse_to_serial_rev_1_1.dsn]
2023-08-09 V1.0.1-rev2
    - Se añade el esquema realizado en formato KiCad.
    - Corregido un error en la conexión a masa del condensador C6 en el esquema en formato TinyCad.
    - Modificadas algunas de las anotaciones en los pins de Arduino en el esquema en formato TinyCad.
    - Añadidos los esquemas de KiCad en formato PDF y PNG.
    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
    [ps2_mouse_to_serial_rev_1_2.dsn, ps2_mouse_to_serial_rev_1_2.kicad_sch]
2023-08-10 v1.0.1-rev2
    - Añadidos los diseños de las PBC para las version "Stand Alone" y "In-a-Box". Estos diseños se han mandado a producción, pero aún no se han verificado.
    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
    [ps2_mouse_to_serial_rev2-B_Cu.gbr, ps2_mouse_to_serial_rev2-B_Mask.gbr, ps2_mouse_to_serial_rev2-B_Paste.gbr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]
2023-08-11 V1.0.1-rev2.1
    - Corregido un error en la colocación del conector PS/2 en la placa "Stand Alone" del proyecto KiCad.
    - Recordar que aún no he podido producir físicamente estas placas, por lo que si vais a producirlas, revisar el proyecto 3 veces en búsqueda de errores.
    [ps2_mouse_to_serial_rev2-B_Cu.gbr, ps2_mouse_to_serial_rev2-B_Mask.gbr, ps2_mouse_to_serial_rev2-B_Paste.gbr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]
2023-08-12 v1.3.0
    - Se utiliza una referencia de versión para el proyecto, independientemente de las versiones de placa o software para facilitar la identificación de la versión actual.
    - Se añade el esquema y diseño de placa para la versión "ISA".
    - Se amplía el ancho de pista en las placas restantes.
    - Sin cambios en el software.
    - Importante! Recordad que aún no he podido verificar en "físico" el diseño de las placas, por lo que recomiendo precaución si van a ser usadas.
    [ps2_mouse_to_serial_port_adapter_ISA_card-B_Cu.gbr, ps2_mouse_to_serial_port_adapter_ISA_card-B_Mask.gbr, ps2_mouse_to_serial_port_adapter_ISA_card-B_Paste.gbr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]
2023-08-12 v1.4.0
    - Pequeños ajustes al tamaño y contorno de la placa ISA.
    - Se han añadido zonas de relleno para GND en la placa ISA.
    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
    [ps2_mouse_to_serial_port_adapter_ISA_card-B_Cu.gbr, ps2_mouse_to_serial_port_adapter_ISA_card-B_Mask.gbr, ps2_mouse_to_serial_port_adapter_ISA_card-B_Paste.gbr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]
2023-08-13 v1.5.0
    - Ajustadas las placas "Stand alone" y "In-a-box" al tamaño standard de
    90x70 mm.
    - Añadidas a estas placas las zonas de relleno a masa (GND).
    - Añadidas las serigrafias con los valores de todos los componentes en todas
    las versiones de las placas.
    [ps2_mouse_to_serial_port_adapter_ISA_card-B_Cu.gbr, ps2_mouse_to_serial_port_adapter_ISA_card-B_Mask.gbr, ps2_mouse_to_serial_port_adapter_ISA_card-B_Paste.gbr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]
2023-08-14 v1.5.1
    - Arreglada la serigrafía del conector MINI-DIN-6 (PS/2), la cual se superponía en algunas zonas de soldado.
    - En todas las placas se añade el símbolo de los agujeros de montaje con el tamaño estándar M3.
    [ps2_mouse_to_serial_port_adapter_ISA_card-B_Cu.gbr, ps2_mouse_to_serial_port_adapter_ISA_card-B_Mask.gbr, ps2_mouse_to_serial_port_adapter_ISA_card-B_Paste.gbr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]
2023-08-24 v1.6.0
    Modificada la librería PS2Mouse para evitar que la placa Arduino se quede colgada al iniciarse si no se detecta el mouse conectado en el puerto PS/2.
    Ahora si la inicialización del mouse falla, se reescanea el puerto a cada segundo.
    De todos modos, os recomiendo que no conectéis o desconectéis el mouse con el adaptador/ordenador encendido, ya que hay la posibilidad de que se causen daños al adaptador o al propio mouse.
2023-08-28 v1.7.0
    - Modificadas las huellas de todas las placas para que los componentes TO92 resulten más fáciles de soldar a mano.
    - Modificadas las conexiones del conector IDC en la placa ISA para poder usar un cable IDC a DB9 comercial, sin necesidad de realizarle modificaciones.
    - Añadido el modelo en formato FreeCad y el archivo STL del soporte para la placa ISA. Estos archivos estan preparados para poder realizar la impresión en 3D del soporte. Se recomienda un in-fill del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
    [PS2_Serial_ISA_Bracket.FCStd, PS2_Serial_ISA_Bracket.stl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]
2023-08-29 v1.7.1
    - Modificado el ancho de la pista de alimentación del puerto PS/2 de la placa ISA.
    [ps2_mouse_to_serial_port_adapter_ISA_card-B_Cu.gbr, ps2_mouse_to_serial_port_adapter_ISA_card-B_Mask.gbr, ps2_mouse_to_serial_port_adapter_ISA_card-B_Paste.gbr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]
2023-08-29 v1.7.1
    - Wrong files upload fix.
    [ps2_mouse_to_serial_port_adapter_ISA_card-B_Cu.gbr, ps2_mouse_to_serial_port_adapter_ISA_card-B_Mask.gbr, ps2_mouse_to_serial_port_adapter_ISA_card-B_Paste.gbr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]
2023-09-06 v1.8.0
    - Dado que algunos modelos de ratón no funcionaban como es debido y en algunos casos ni encendían (PERIMICE-209), se analiza la librería usada de Arduino para la interfaz con el puerto PS/2. Viendo q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
    - Ahora todos los comandos que se envían al ratón se verifican.
    - Se añade una secuencia de encendido para activar algunos modelos de ratón que antes no funcionaban, como el PERIMICE-209.
    - Con la librería personalizada, se añade la opción de detectar si el ratón es compatible con Microsoft IntelliMouse y este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

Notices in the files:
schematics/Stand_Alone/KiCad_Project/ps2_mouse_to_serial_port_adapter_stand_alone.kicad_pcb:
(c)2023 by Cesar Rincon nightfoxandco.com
